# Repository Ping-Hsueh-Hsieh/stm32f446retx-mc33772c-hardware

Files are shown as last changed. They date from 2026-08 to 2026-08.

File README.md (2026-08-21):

# TODO

- [x] fill region: In1.Cu with GND
- [x] change 16MHz crystal to 8MHz, since 8MHz is cheaper and more available.
- [x] USB OTG FS: VBUS senisng
- [ ] stitching & fencing vias
- [x] shrink the board

# Sources

- [step-by-step tutorial](https://github.com/gt-marine-robotics-group/kicad-tutorial)
- [video](https://fedevel.com/blog/kicad-stm32-hardware-design-an-overview-in-20-minutes-phils-lab-15)
- [kicad footprints](https://gitlab.com/kicad/libraries/kicad-footprints)
- [reverse engineering KiCad Project from Gerber file](https://forum.kicad.info/t/reverse-engineering-kicad-project-from-gerber-files/30903)
- [STM32H742Vx 144 template](https://github.com/dmitrystu/nuco-v/blob/master/nuco-v.pdf)
- [STM32F446RETx sample](https://github.com/r4hulrr/stm-32-bms)

# ST-LINK

Test on NUCLEO-F446ZE with [configuration](./figs/how-to-connect-external-stlink-to-nucleo-f446ze.png) from [post](https://community.st.com/stm32-mcus-products-25/debugging-stm32f446ze-nucleo-swd-with-external-st-link-v2-155755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).
```
CN4.2 --> SWCLK
CN4.4 --> SWDIO
CN6.3 --> GND
```
with these pins connected, external ST-LINK V2 can be connected, debugging, even SWD with ITM.

# USB OTG FS

[VBUS sensing](https://community.st.com/stm32-mcus-60/management-of-vbus-sensing-for-usb-device-design-93)

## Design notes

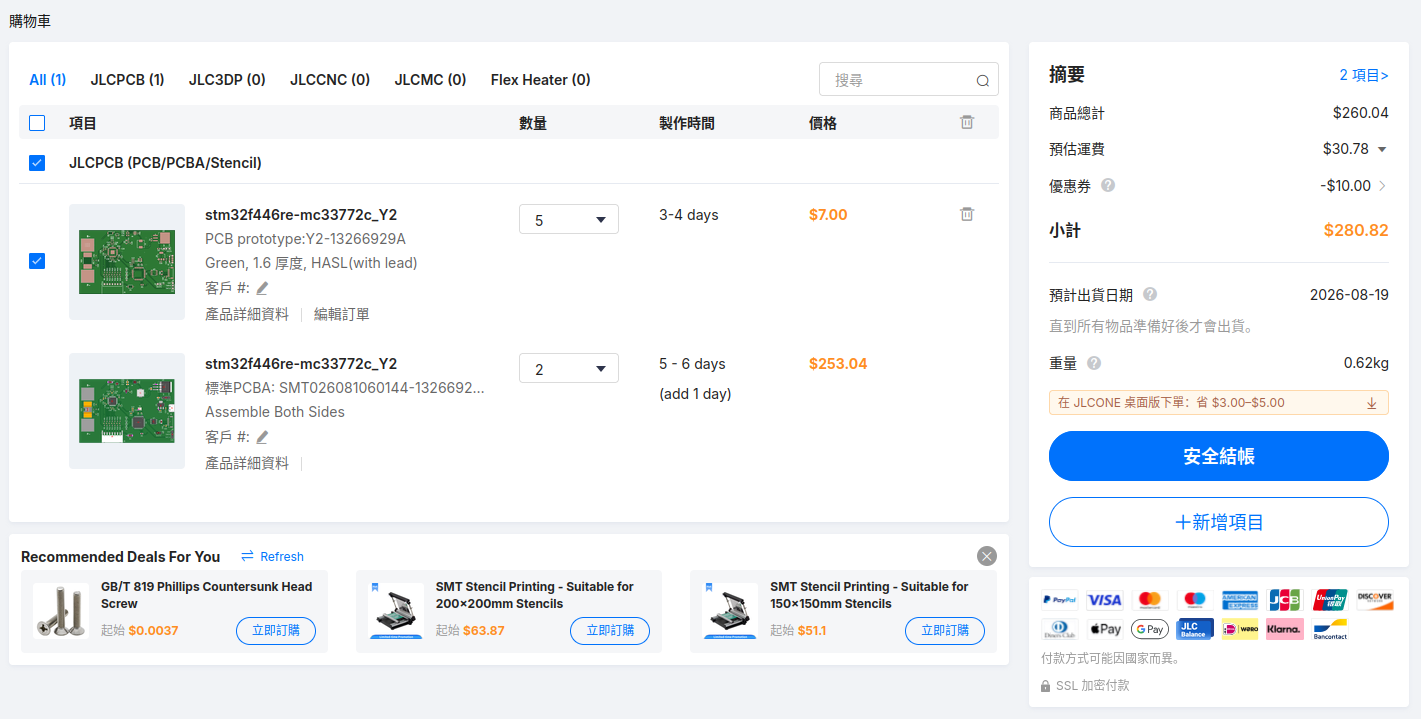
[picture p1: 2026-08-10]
figs/JLCPCB.png

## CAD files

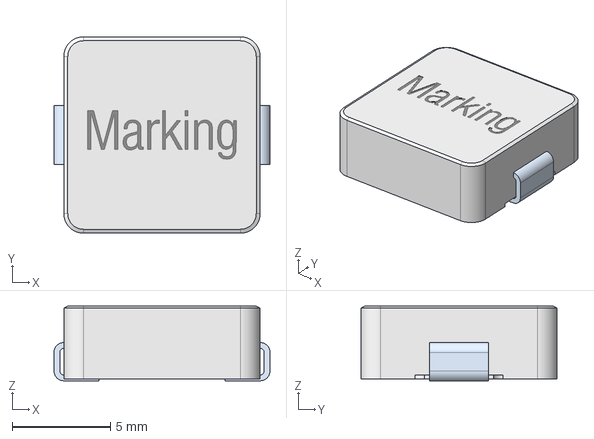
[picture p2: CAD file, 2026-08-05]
74437368033/WE-LHMI-1040_74437368033.stp
11.0 x 10.0 x 3.80 mm

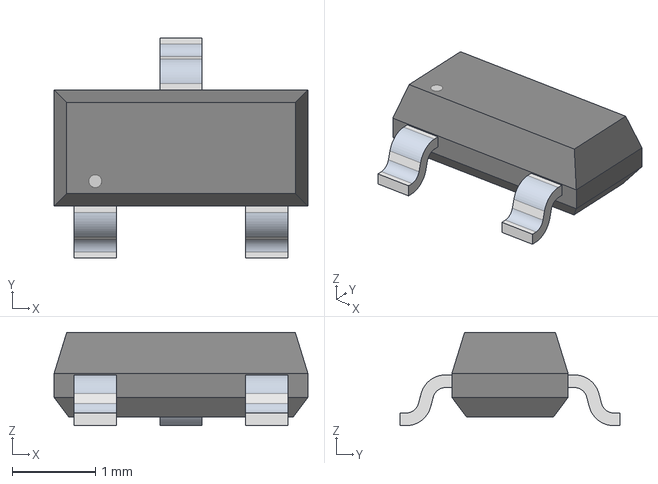
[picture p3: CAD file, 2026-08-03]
BAS40LT1/SOT-23-3_1P4X3P040_ONS.iges
3.05 x 2.64 x 1.12 mm

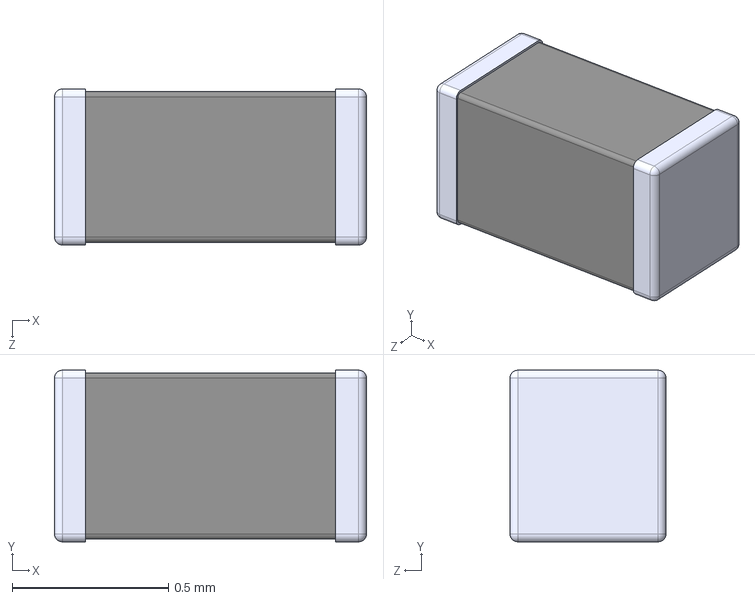
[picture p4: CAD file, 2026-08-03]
NTCG104BH103HT1/NTCG104BH103HT1.step
1.00 x 0.55 x 0.5 mm

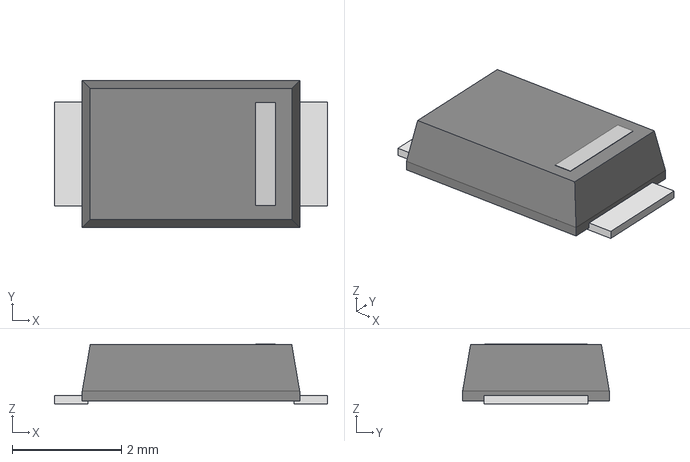
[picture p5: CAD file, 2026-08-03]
PMEG3050EP_115/SDO_CFP5_SOD128_NEX.iges
5.00 x 2.69 x 1.10 mm

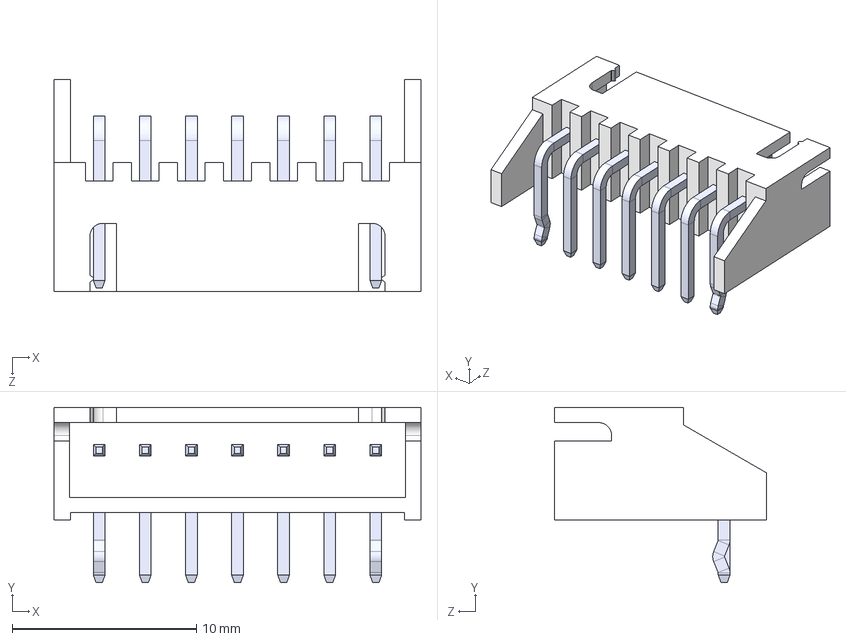
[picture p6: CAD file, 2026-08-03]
S7B_XH_A/S7B-XH-A.step
19.9 x 9.50 x 11.5 mm
SxB-XH-A_7
pin^SxB-XH-A ass_bent x 2
pin^SxB-XH-A ass x 5

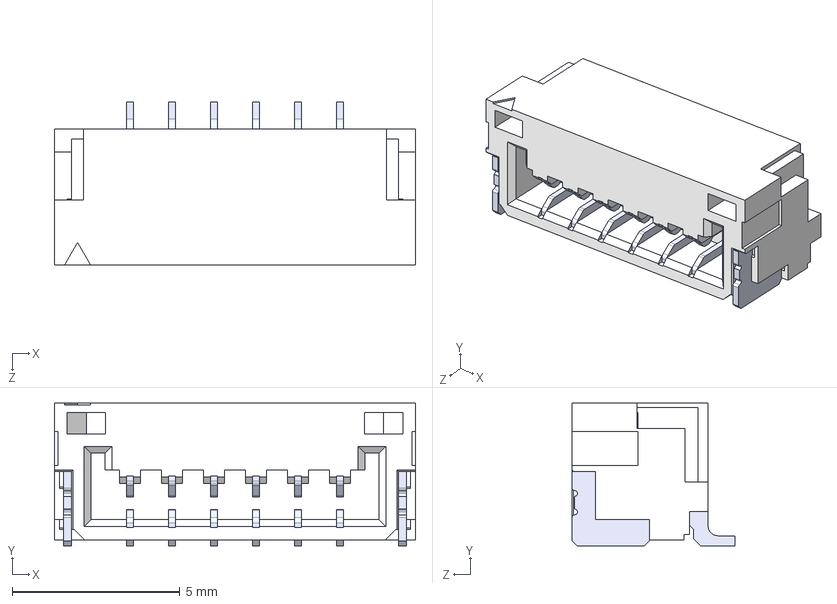
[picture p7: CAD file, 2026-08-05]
SM06B_GHS_TB/SM06B-GHS-TB.step
10.8 x 4.25 x 4.85 mm
SMxB-GHS-TB_06
pin x 6

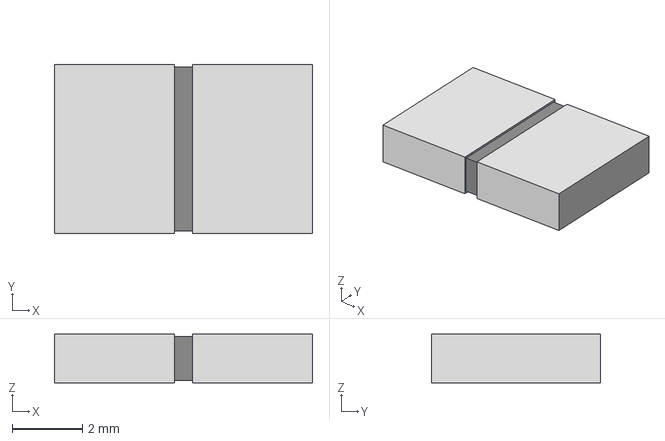
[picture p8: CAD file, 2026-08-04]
WSBS8518L1000JK/WSBS8518_VIS.iges
7.37 x 4.83 x 1.40 mm

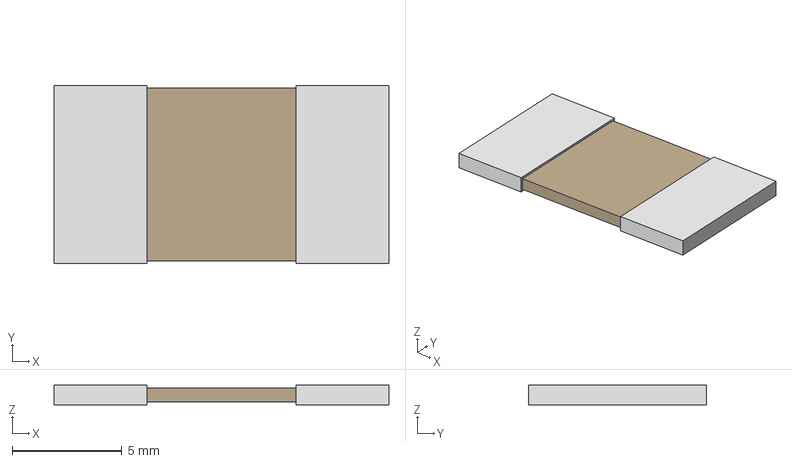
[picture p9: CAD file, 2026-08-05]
WSLP5931L1000FEA/WSLP5931L1000FEA.step
15.3 x 8.13 x 0.889 mm

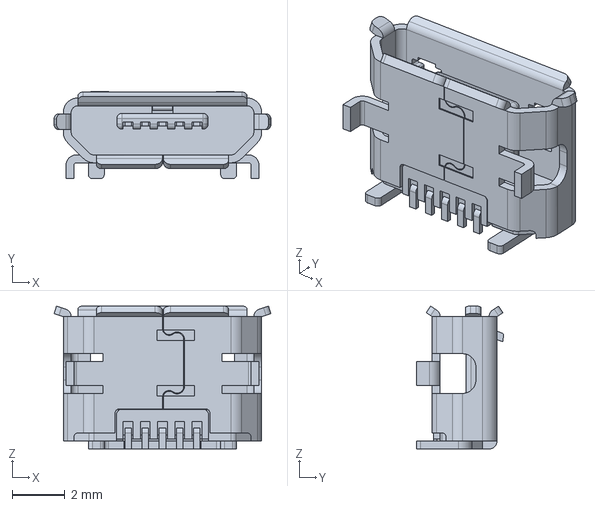
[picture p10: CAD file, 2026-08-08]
1050170001/1050170001.stp
8.20 x 3.30 x 5.40 mm

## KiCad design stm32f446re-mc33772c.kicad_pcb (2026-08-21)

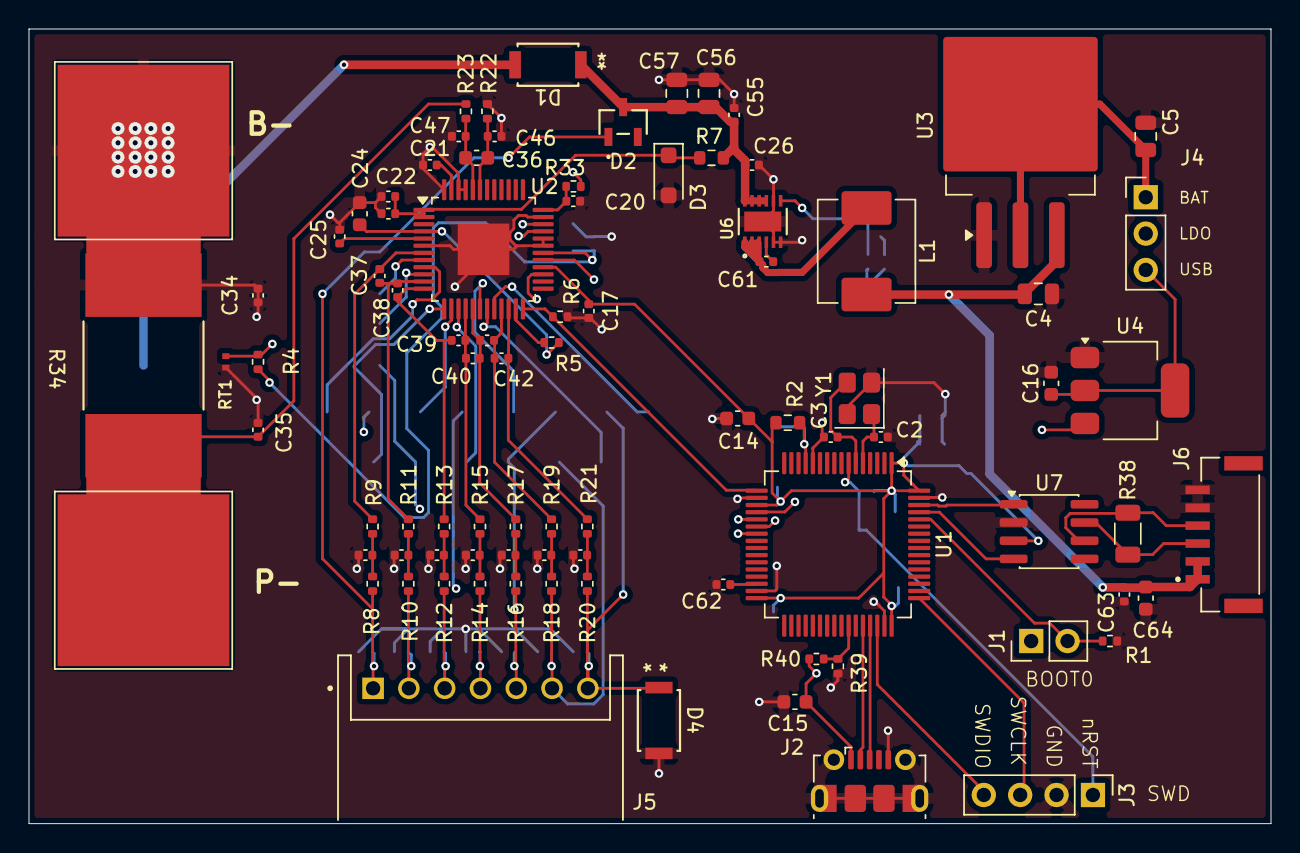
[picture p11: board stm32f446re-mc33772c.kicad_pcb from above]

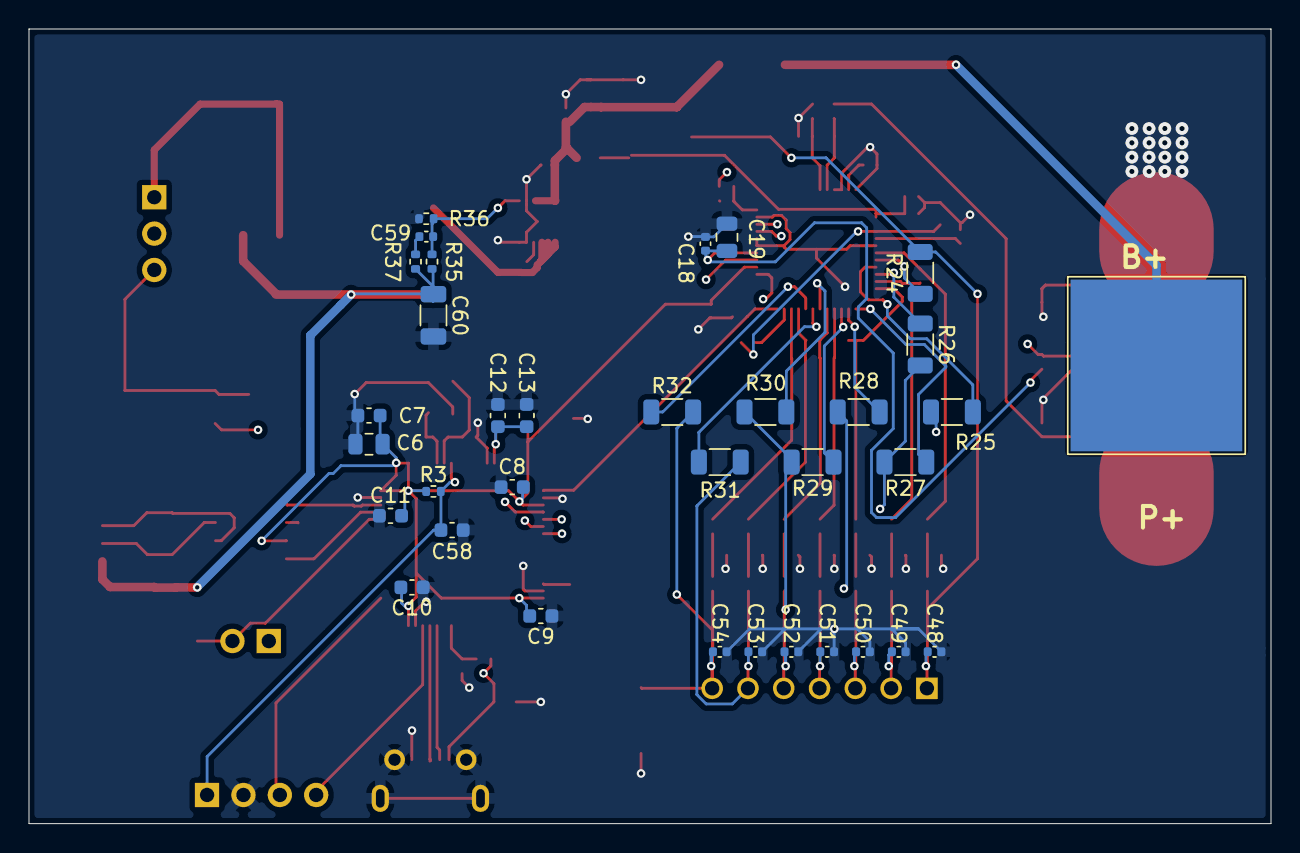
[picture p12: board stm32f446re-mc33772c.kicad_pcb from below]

Board: 4 copper layers, 86.8 x 55.5 mm, 122 parts (34 on the bottom side), 73 nets.

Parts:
C2, C3: 12p; C_0402_1005Metric
C4, C5, C6: 10u; C_0805_2012Metric
C7, C8, C9, C10, C11, C58: 100n; C_0603_1608Metric
C12: 10n; C_0603_1608Metric
C13, C14, C64: 1u; C_0603_1608Metric
C15, C16: 22u; C_0603_1608Metric
C17, C18, C27, C28, C29, C30, C31, C32, C33, C55, C61, C63: 100n; C_0402_1005Metric
C19: 2.2u; C_0805_2012Metric
C20: 1200p; C_0402_1005Metric
C21, C26, C34, C35, C46, C47, C48, C49, C50, C51, C52, C53, C54: 0.047u; C_0402_1005Metric
C22: 0.22u; C_0402_1005Metric
C23: 1000p; C_0402_1005Metric
C24: 0.47u; C_0603_1608Metric
C25, C37, C38, C39, C40, C41, C42: 0.01u; C_0402_1005Metric
C36: 6.8u; C_0603_1608Metric
C56, C57: 4.7u; C_0805_2012Metric
C59: 22p; C_0402_1005Metric
C60: 33u; C_1206_3216Metric
C62: 4.7u; C_0402_1005Metric
D1, D4: PMEG3050EP_115
D2: BAS40LT1G; BAS40LT1
D3: BZT52-C39_R1_00001; D_SOD-123F
J1: Conn_01x02; PinHeader_1x02_P2.54mm_Vertical
J2: USB_B_Micro; USB_Micro-B_Molex-105017-0001
J3: Conn_01x04; PinHeader_1x04_P2.54mm_Vertical
J4: Conn_01x03; PinHeader_1x03_P2.54mm_Vertical
J5: S7B-XH-A; JST_S7B-XH-A
J6: SM06B-GHS-TB; JST_SM06B-GHS-TB
L1: 3.3uH; PSPMAA0605H-3R3M-ANP
PAD1, PAD3, PAD4: pad; INPUT_PAD
R1, R3, R39: 10k; R_0402_1005Metric
R2: 120R; R_0603_1608Metric
R4, R5, R6: 10K; R_0402_1005Metric
R7: 6.8; R_0603_1608Metric
R8, R10, R12, R14, R16, R18, R20: 3.0K; R_0402_1005Metric
R9, R11, R13, R15, R17, R19, R21: 2.0K; R_0402_1005Metric
R22, R23: 127; R_0402_1005Metric
R24, R26, R27, R29, R30, R32: 68; R_1206_3216Metric
R25, R28, R31: 16; R_1206_3216Metric
R33: 3.3K; R_0402_1005Metric
R34: WSLP5931L1000FEA
R35: 100k; R_0402_1005Metric
R36: 19.1k; R_0402_1005Metric
R37: 1k; R_0402_1005Metric
R38: 120; R_1206_3216Metric
R40: 4.7k; R_0402_1005Metric
RT1: NTCG104BH103HT1; THERM_NTCG104BH103HT1
U1: STM32F446RET6; LQFP-64_10x10mm_P0.5mm
U2: MC33772CTP1AE; LQFP-48-1EP_7x7mm_P0.5mm_EP3.6x3.6mm
U3: LD1086D2M33TR; TO-263-3_TabPin2
U4: AMS1117-3.3; SOT-223-3_TabPin2
U6: LMR51450SDRRR
U7: SN65HVD232; SOIC-8_3.9x4.9mm_P1.27mm
Y1: 8MHz; Crystal_SMD_3225-4Pin_3.2x2.5mm

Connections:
AFE_CB_1: R32.1, U2.20 (CB_1)
AFE_CB_2: R30.1, U2.18 (CB_2)
AFE_CB_2:1_C: R31.1, U2.19 (CB_2:1_C)
AFE_CB_3: R29.1, U2.15 (CB_3)
AFE_CB_4: R27.1, U2.13 (CB_4)
AFE_CB_4:3_C: R28.1, U2.14 (CB_4:3_C)
AFE_CB_5: R26.1, U2.10 (CB_5)
AFE_CB_6: R24.1, U2.8 (CB_6)
AFE_CB_6:5_C: R25.1, U2.9 (CB_6:5_C)
AFE_CT_1: C41.2, C42.1, R19.1, U2.21 (CT_1)
AFE_CT_2: C40.2, C41.1, R17.1, U2.17 (CT_2)
AFE_CT_3: C39.2, C40.1, R15.1, U2.16 (CT_3)
AFE_CT_4: C38.2, C39.1, R13.1, U2.12 (CT_4)
AFE_CT_5: C37.2, C38.1, R11.1, U2.11 (CT_5)
AFE_CT_6: C37.1, R9.1, U2.7 (CT_6)
AFE_CT_REF: C42.2, R21.1, U2.22 (CT_REF)
AFE_ISENSE+: C36.1, C46.2, R22.1, U2.43 (ISENSE+)
AFE_ISENSE-: C36.2, C47.2, R23.1, U2.44 (ISENSE-)
AFE_VCOM: C18.2, C19.2, R4.1, U2.30 (VCOM)
AFE_VPRE: C24.1, R5.2, U2.4 (VPRE)
AFE_VPWR: C22.1, C23.1, D3.1 (K), R7.2, U2.1 (VPWR2), U2.2 (VPWR1)
BAT_3.3V: C5.1, J4.1, U3.2 (OUT)
BP-C1M: C54.1, D4.1, J5.7, R20.2, R32.2
BP-C1P: C53.1, J5.6, R18.2, R31.2
BP-C2P: C52.1, J5.5, R16.2, R29.2, R30.2
BP-C3P: C51.1, J5.4, R14.2, R28.2
BP-C4P: C50.1, J5.3, R12.2, R26.2, R27.2
BP-C5P: C49.1, J5.2, R10.2, R25.2
BP-C6P: C48.1, D2.1 (A), J5.1, R8.2, R24.2
Buck_5V: C4.1, C60.1, C63.1, C64.1, J6.1, J6.2, L1.2, R35.1, R37.1, U3.3 (IN)
CANH: J6.3, R38.1, U7.7 (CANH)
CANL: J6.4, R38.2, U7.6 (CANL)
CAN_RX: U1.61 (CAN1_RX), U7.4 (R)
CAN_TX: U1.62 (CAN1_TX), U7.1 (D)
D+: J2.3 (D+), U1.45 (USB_OTG_FS_DP)
D-: J2.2 (D-), U1.44 (USB_OTG_FS_DM)
LDO_3.3V: C6.2, C7.2, C8.2, C9.2, C10.2, C11.2, C14.1, C17.2, J1.1, J4.2, R2.2, R3.1, U1.1 (VBAT), U1.19 (VDD), U1.32 (VDD), U1.48 (VDD), U1.64 (VDD), U2.28 (VDDIO), U7.3 (VCC)
MC33772C_RESET: R6.1, U1.17 (PA3), U2.24 (RESET)
NTC_0: C20.1, R33.1, U2.36 (AN0/GPIO0)
unnamed: C27.1, R8.1, R9.2
unnamed: C28.1, R10.1, R11.2
unnamed: C29.1, R12.1, R13.2
unnamed: C30.1, R14.1, R15.2
unnamed: C31.1, R16.1, R17.2
unnamed: C32.1, R18.1, R19.2
unnamed: C33.1, R20.1, R21.2
unnamed: C59.1, R37.2
unnamed: J1.2, R1.1, U1.60 (BOOT0)
unnamed: R4.2, R33.2, RT1.1
unnamed: R39.1, R40.2, U1.42 (USB_OTG_FS_VBUS)
unnamed: C2.1, U1.5 (PH0), Y1.1
unnamed: C3.1, U1.6 (PH1), Y1.3
unnamed: C62.1, U1.30 (VCAP_1)
unnamed: C12.1, C13.1, R2.1, U1.13 (VDDA)
unnamed: R5.1, U2.23 (SPI_COM_EN)
unnamed: C21.2, U2.47 (VANA)
unnamed: C61.1, U6.4 (BOOT)
unnamed: C59.2, R35.2, R36.1, U6.7 (FB)
unnamed: C61.2, L1.1, U6.1 (SW), U6.2 (SW__1), U6.3 (SW__2)
Pack-: C35.2, PAD4.1 (1_1), R23.2, R34.2
Pack_24V: D1.2, PAD1.1 (1_1)
Rsense_P: C2.2, C3.2, C4.2, C5.2, C6.1, C7.1, C8.1, C9.1, C10.1, C11.1, C12.2, C13.2, C14.2, C15.2, C16.2, C17.1, C18.1, C19.1, C20.2, C21.1, C22.2, C23.2, C24.2, C25.2, C26.2, C27.2, C28.2, C29.2, C30.2, C31.2, C32.2, C33.2, C34.1, C34.2, C35.1, C46.1, C47.1, C48.2, C49.2, C50.2, C51.2, C52.2, C53.2, C54.2, C55.2, C56.2, C57.2, C58.1, C60.2, C62.2, C63.2, C64.2, D3.2 (A), D4.2, J2.5 (GND), J2.SH (Shield), J3.2, J6.5, J6.6, PAD3.1 (1_1), R1.2, R6.2, R22.2, R34.1, R36.2, R39.2, RT1.2, U1.12 (VSSA), U1.18 (VSS), U1.31 (VSS), U1.47 (VSS), U1.63 (VSS), U2.6 (GNDCP), U2.31 (CGND), U2.32 (RDTX_OUT-), U2.35 (RDTX_OUT+), U2.45 (AGND), U2.46 (DGND), U2.48 (GNDSUB), U2.49 (GNDFLAG), U3.1 (ADJ/GND), U4.1 (GND), U6.5 (PG), U6.6 (RT), U6.8 (AGND), U6.13 (PGND), U7.2 (GND), Y1.2 (G), Y1.4 (G)
SPI1_MISO: U1.22 (SPI1_MISO), U2.27 (SO)
SPI1_MOSI: U1.23 (SPI1_MOSI), U2.34 (SI/RDTX_IN+)
SPI1_NSS: U1.20 (SPI1_NSS), U2.29 (CSB)
SPI1_SCK: U1.21 (SPI1_SCK), U2.33 (SCLK/RDTX_IN-)
SWCLK: J3.3, U1.49 (SYS_JTCK-SWCLK)
SWDIO: J3.4, U1.46 (SYS_JTMS-SWDIO)
USB_3.3V: C16.1, J4.3, U4.2 (VO)
VBAT_PROT_24V: C26.1, C55.1, C56.1, C57.1, D1.1, D2.3 (K), R7.1, U6.9 (EN), U6.10 (VIN), U6.11 (VIN__1), U6.12 (VIN__2)
VBUS_5V: C15.1, J2.1 (VBUS), R40.1, U4.3 (VI)
VCP: C25.1, U2.5 (VCP)
nRST: C58.2, J3.1, R3.2, U1.7 (NRST)

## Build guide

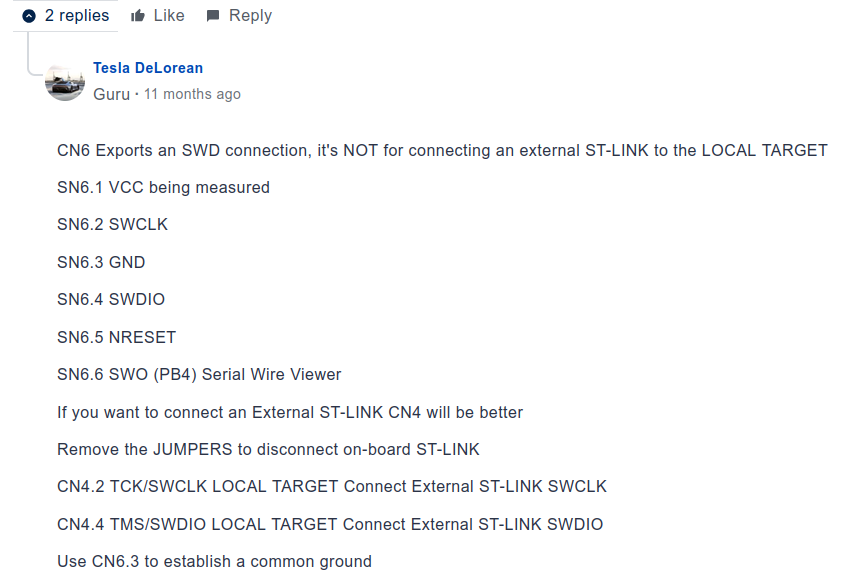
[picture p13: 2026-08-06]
figs/how-to-connect-external-stlink-to-nucleo-f446ze.png

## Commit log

2026-07-28 kind of get someing going
    [stm32f446re-mc33772c.kicad_pcb, stm32f446re-mc33772c.kicad_sch]
2026-07-29 add LDO for 3.3V VBAT/VDD
    [stm32f446re-mc33772c.kicad_sch]
2026-07-29 change LDO to LD1086D2M33TR for 1.5A
    [stm32f446re-mc33772c.kicad_sch]
2026-08-03 TODO: STLINK for stm32f446re
    [mc33772c.kicad_sch, stm32f446re-mc33772c.kicad_sch]
2026-08-03 kicad library
2026-08-03 feat: STM32F446RE basically done, MC33772C remains
    [mc33772c.kicad_sch, stm32f446re-mc33772c.kicad_sch]
2026-08-03 MC33772C basically done. connector need update.
    [NTCG104BH103HT1.step, S7B-XH-A.step, SDO_CFP5_SOD128_NEX.iges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]
2026-08-04 schematic done
    [WSBS8518_VIS.iges, mc33772c.kicad_sch, power.kicad_sch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]
2026-08-04 start to PCB drawing, but error due to missing footprint
    [power.kicad_sch, stm32f446re-mc33772c.kicad_pcb]
2026-08-04 feat: CAN/BUCK
    1. CAN transceiver added
    2. Buck added 24V -> 5V
    3. LDO 5V -> 3.3V
    [LMR51450SDRRR.step, power.kicad_sch, stm32f446re-mc33772c.kicad_sch]
2026-08-05 CAN/BUCK/CONNECTOR done
    [SM06B-GHS-TB.step, stm32f446re-mc33772c.kicad_sch]
2026-08-05 fullup the annotation for update PCB from Schematics
    [WE-LHMI-1040_74437368033.stp, WSLP5931L1000FEA.step, mc33772c.kicad_sch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]
2026-08-06 update annotation
    [power.kicad_sch, stm32f446re-mc33772c.kicad_sch]
2026-08-06 correct R to 0402
    [power.kicad_sch]
2026-08-06 all the components at the right place
    [stm32f446re-mc33772c.kicad_pcb]
2026-08-06 better the placement
    [stm32f446re-mc33772c.kicad_pcb]
2026-08-06 good placement
    [stm32f446re-mc33772c.kicad_pcb, stm32f446re-mc33772c.kicad_sch]
2026-08-06 GND the whole in2.Cu
    [stm32f446re-mc33772c.kicad_pcb]
2026-08-07 start routing
    [stm32f446re-mc33772c.kicad_pcb]
2026-08-07 freerouting weird wiring
    [stm32f446re-mc33772c.dsn, stm32f446re-mc33772c.kicad_pcb]
2026-08-07 add pad for B and P
    [power.kicad_sch, stm32f446re-mc33772c.kicad_pcb]
2026-08-07 GND, power_flag
    1. F.Cu and B.Cu fill zone with GND
    2. add power_flag
    [power.kicad_sch, stm32f446re-mc33772c.kicad_pcb, stm32f446re-mc33772c.kicad_sch]
2026-08-07 update oscillator datasheet
    [stm32f446re-mc33772c.kicad_sch]
2026-08-08 no error in DRC
    [DRR0012G.stp, LMR51450SDRRR.step, stm32f446re-mc33772c.kicad_pcb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]
2026-08-08 DRC: remove silkscreen warning
    [stm32f446re-mc33772c.kicad_pcb]
2026-08-08 update 3D model
    [1050170001.stp, stm32f446re-mc33772c.kicad_pcb]
2026-08-08 feat: change B+/P+ to B.Cu and onto one pad
    [power.kicad_sch, stm32f446re-mc33772c.kicad_pcb]
2026-08-08 add LCPC Part #
    [mc33772c.kicad_sch, power.kicad_sch, stm32f446re-mc33772c.kicad_pcb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]
2026-08-08 update for JLCPCB with LCSC part #
    [mc33772c.kicad_sch, power.kicad_sch, stm32f446re-mc33772c.kicad_pcb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]
2026-08-08 update PCB for jlcpcb toolkit
    [stm32f446re-mc33772c.kicad_pcb]
2026-08-08 export to JLCPCB
    [mc33772c.kicad_sch, power.kicad_sch, stm32f446re-mc33772c.kicad_pcb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]
2026-08-08 for PCBWay
    [mc33772c.kicad_sch, power.kicad_sch, stm32f446re-mc33772c.kicad_pcb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]
2026-08-08 ignore kicad -> jlcpcb files
2026-08-10 add testpoint
    [stm32f446re-mc33772c.kicad_pcb, stm32f446re-mc33772c.kicad_sch]
2026-08-10 add for test points
    [mc33772c.kicad_sch, power.kicad_sch, stm32f446re-mc33772c.kicad_pcb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]
2026-08-19 fix: VCAP_1 4.7uF, In1.Cu fill GND
    [stm32f446re-mc33772c.kicad_pcb, stm32f446re-mc33772c.kicad_sch]
2026-08-19 update silkscreen, make 6pin closer to edge
    [stm32f446re-mc33772c.kicad_pcb]
2026-08-19 change crystal from 16MHz to 8MHz
    [stm32f446re-mc33772c.kicad_pcb, stm32f446re-mc33772c.kicad_sch]
2026-08-19 add USB OTG FS VBUS sensing
    [stm32f446re-mc33772c.kicad_pcb, stm32f446re-mc33772c.kicad_sch]
2026-08-19 remove DRC error/warning
    [stm32f446re-mc33772c.kicad_pcb]
2026-08-20 doc(README): add todo - shrink the board
2026-08-20 make 5V thicker
    [stm32f446re-mc33772c.kicad_pcb]
2026-08-20 C55 -> 50V
    [stm32f446re-mc33772c.kicad_pcb]
2026-08-21 make everything closer
    [stm32f446re-mc33772c.kicad_pcb]
2026-08-21 cleanup sch
    [stm32f446re-mc33772c.kicad_pcb, stm32f446re-mc33772c.kicad_sch]
2026-08-21 remove D+ pullup
    [stm32f446re-mc33772c.kicad_pcb]
2026-08-21 shrink, SWD
    [mc33772c.kicad_sch, power.kicad_sch, stm32f446re-mc33772c.kicad_pcb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]
